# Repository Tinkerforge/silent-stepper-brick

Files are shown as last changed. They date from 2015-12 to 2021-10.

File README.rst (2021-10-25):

Silent Stepper Brick
====================

This repository contains the firmware source code and the hardware design
files. The documentation generator configs can be found at
https://github.com/Tinkerforge/generators

Repository Content
------------------

software/:
 * examples/: Examples for all supported languages
 * build/: Compiled files
 * src/: Source code of firmware
 * Makefile: Makefile to build project

hardware/:
 * Contains KiCad project files and additionally schematics as PDF

datasheets/:
 * Contains datasheets for sensors and complex ICs that are used

Hardware
--------

The hardware is designed with the open source EDA Suite KiCad
(http://www.kicad.org). Before you are able to open the files,
you have to install the Tinkerforge kicad-libraries
(https://github.com/Tinkerforge/kicad-libraries). You can either clone
them directly in hardware/ or clone them in a separate folder and
symlink them into hardware/
(ln -s kicad_path/kicad-libraries project_path/hardware). After that you
can open the .pro file in hardware/ with KiCad and from there view and
modify the schematics and the PCB layout.

Software
--------

If you want to do your own Brick/Bricklet firmware development we highly
recommend that you use our build environment setup script and read the
tutorial (https://www.tinkerforge.com/en/doc/Tutorials/Tutorial_Build_Environment/Tutorial.html).

To compile the C code we recommend you to install the newest GNU Arm Embedded
Toolchain (https://launchpad.net/gcc-arm-embedded/+download).
You also need to install bricklib (https://github.com/Tinkerforge/bricklib).

You can either clone it directly in software/src/ or clone it in a
separate folder and symlink it into software/src/
(ln -s bricklib_path/bricklib project_path/software/src/). Finally make sure to
have CMake installed (http://www.cmake.org/cmake/resources/software.html).

After that you can build the firmware by invoking make in software/.
The firmware (.bin) can then be found in software/build/ and uploaded
with brickv (click button "Flashing" on start screen).

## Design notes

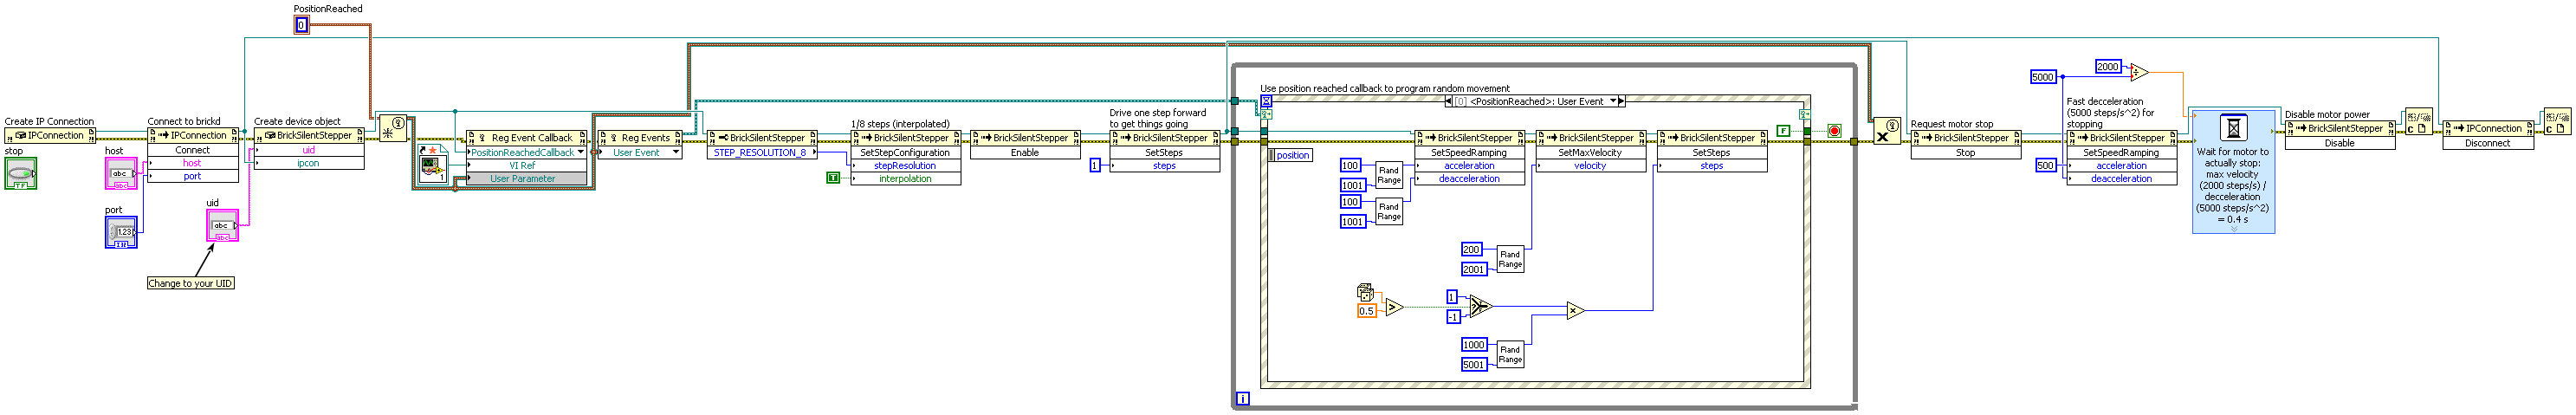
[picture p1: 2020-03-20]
software/examples/labview/Example Callback.vi.png

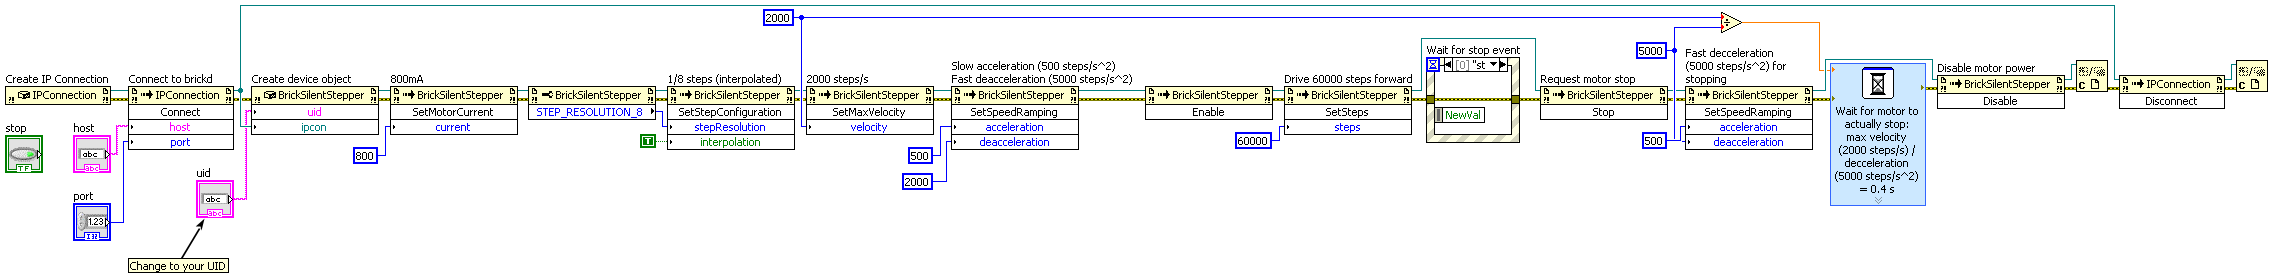
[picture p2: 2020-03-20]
software/examples/labview/Example Configuration.vi.png

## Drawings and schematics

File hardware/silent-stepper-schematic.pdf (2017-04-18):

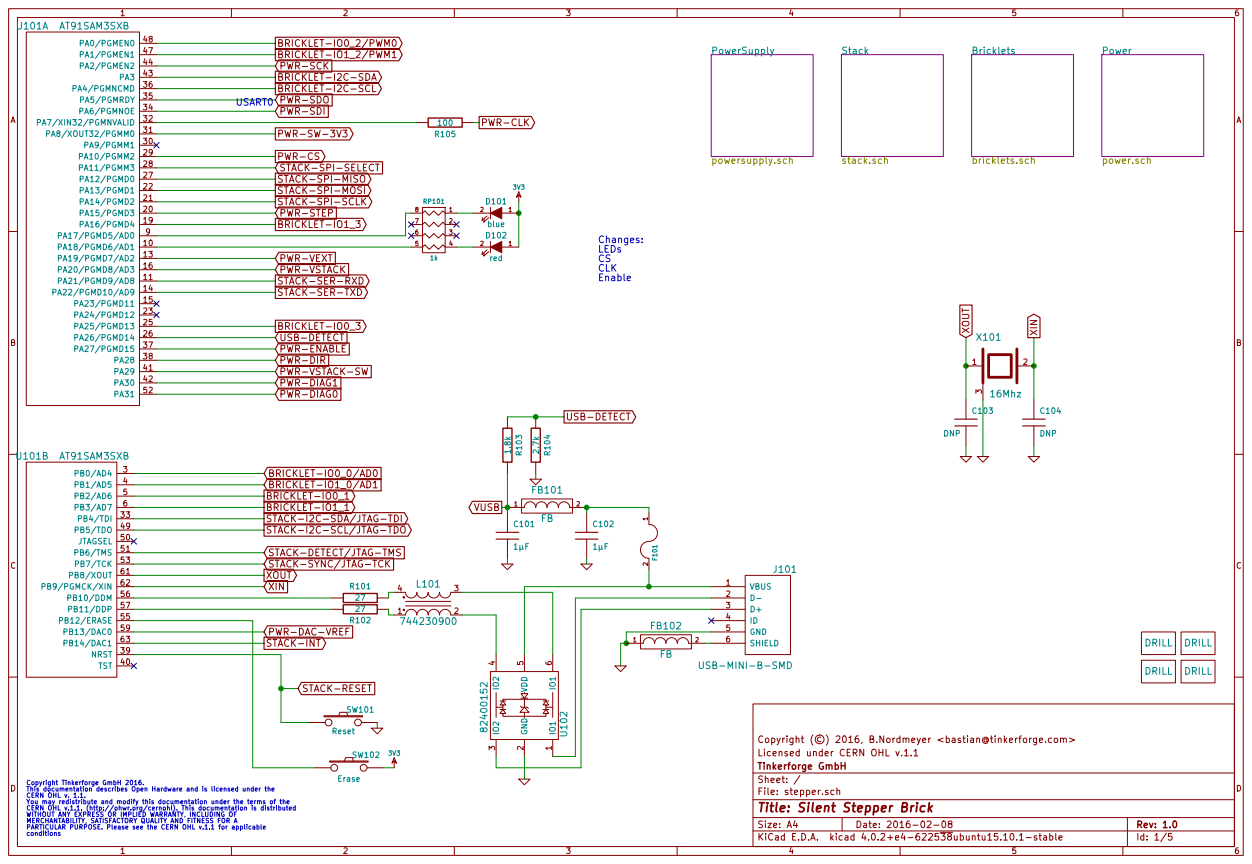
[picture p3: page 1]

BRICKLET-IO0_0/AD0
BRICKLET-IO1_0/AD1
BRICKLET-IO0_1
BRICKLET-IO1_1
STACK-I2C-SDA/JTAG-TDI
STACK-I2C-SCL/JTAG-TDO

STACK-DETECT/JTAG-TMS
STACK-SYNC/JTAG-TCK
XOUT
XIN

Licensed under CERN OHL v.1.1 Copyright (©) 2016, B.Nordmeyer <bastian@tinkerforge.com>

File: stepper.sch Sheet: / Tinkerforge GmbH

Copyright Tinkerforge GmbH 2016. This documentation describes Open Hardware and is licensed under the CERN OHL v. 1.1. You may redistribute and modify this documentation under the terms of the CERN OHL v.1.1. (http://ohwr.org/cernohl). This documentation is distributed WITHOUT ANY EXPRESS OR IMPLIED WARRANTY, INCLUDING OF MERCHANTABILITY, SATISFACTORY QUALITY AND FITNESS FOR A

Id: 1/5 Title: Silent Stepper Brick

PARTICULAR PURPOSE. Please see the CERN OHL v.1.1 for applicable
conditions

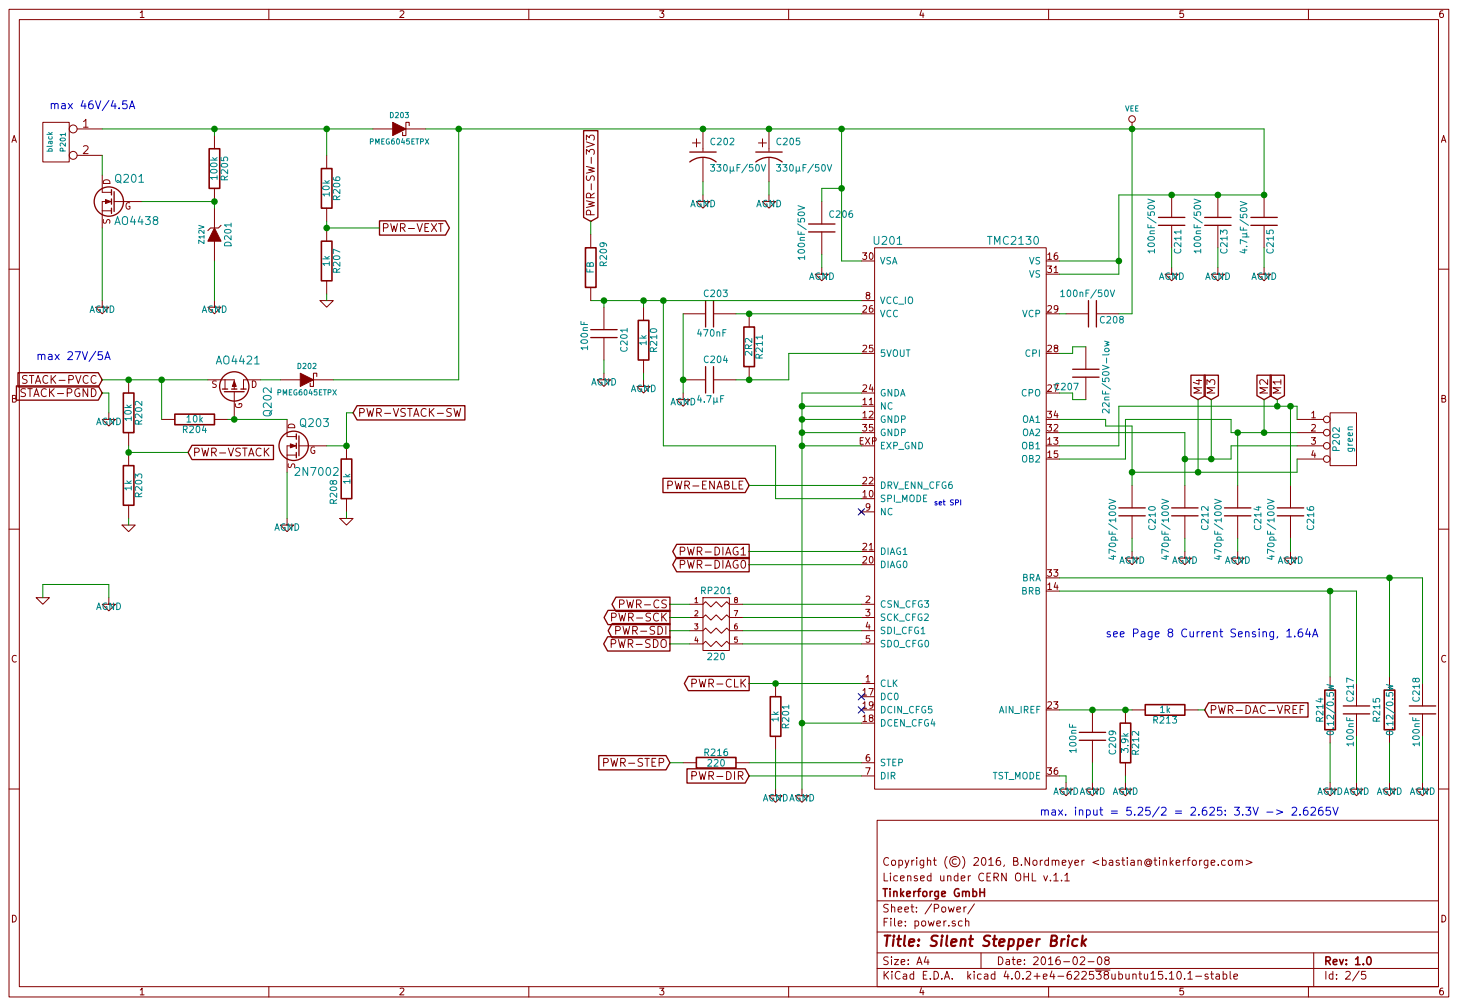
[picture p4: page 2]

File: power.sch Sheet: /Power/ Tinkerforge GmbH

Id: 2/5 Title: Silent Stepper Brick

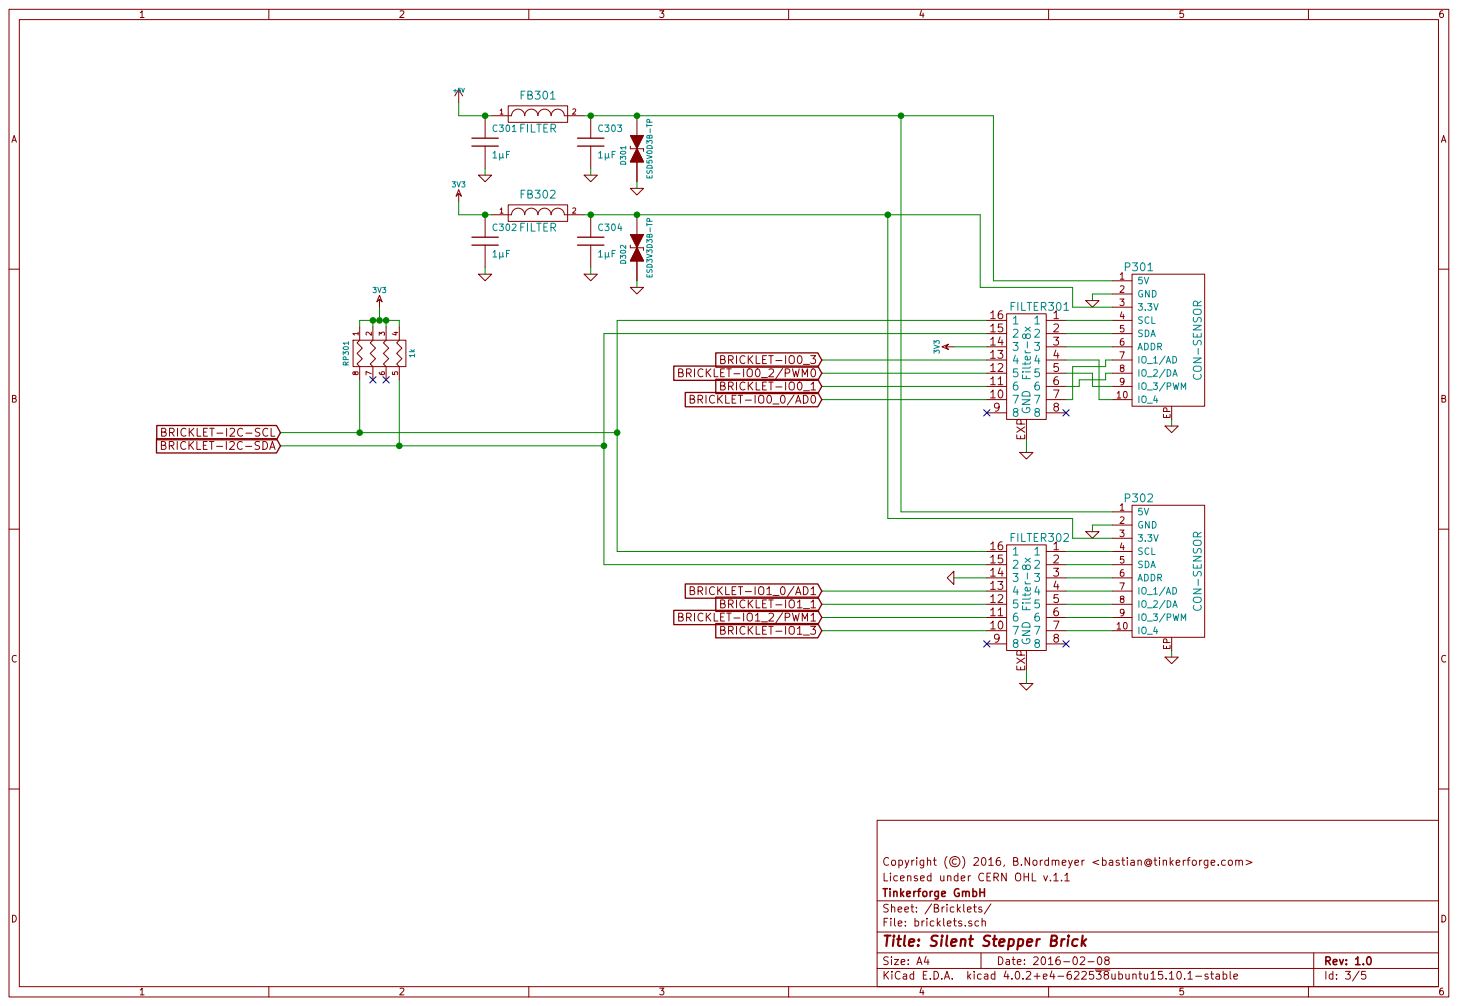
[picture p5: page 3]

File: bricklets.sch Sheet: /Bricklets/ Tinkerforge GmbH

Id: 3/5 Title: Silent Stepper Brick

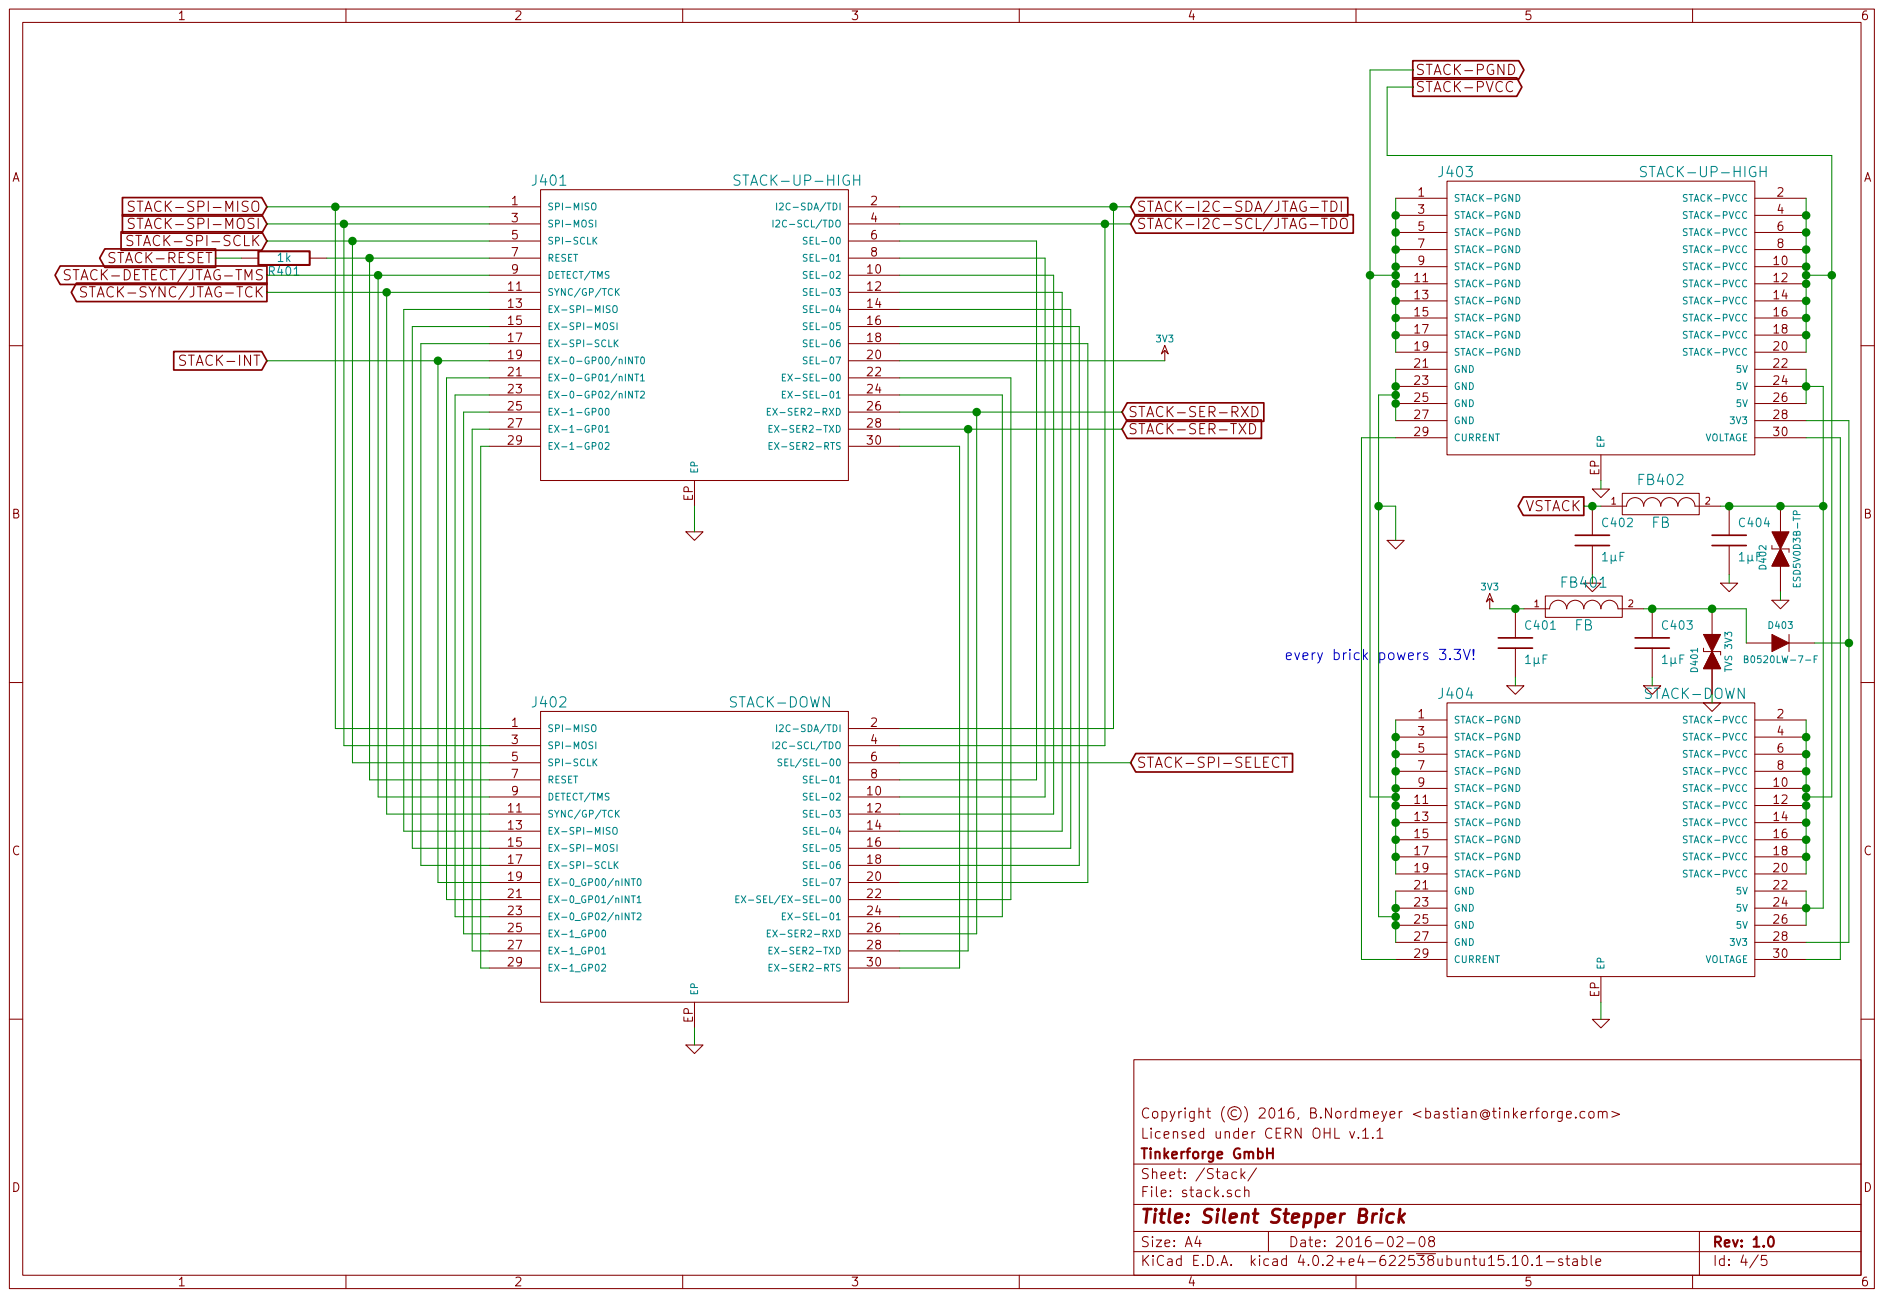
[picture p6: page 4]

STACK-SPI-MISO
STACK-SPI-MOSI
STACK-SPI-SCLK
STACK-RESET
STACK-DETECT/JTAG-TMS
STACK-SYNC/JTAG-TCK

STACK-I2C-SDA/JTAG-TDI
STACK-I2C-SCL/JTAG-TDO

Licensed under CERN OHL v.1.1 Copyright (©) 2016, B.Nordmeyer <bastian@tinkerforge.com>

File: stack.sch Sheet: /Stack/ Tinkerforge GmbH

Id: 4/5 Title: Silent Stepper Brick

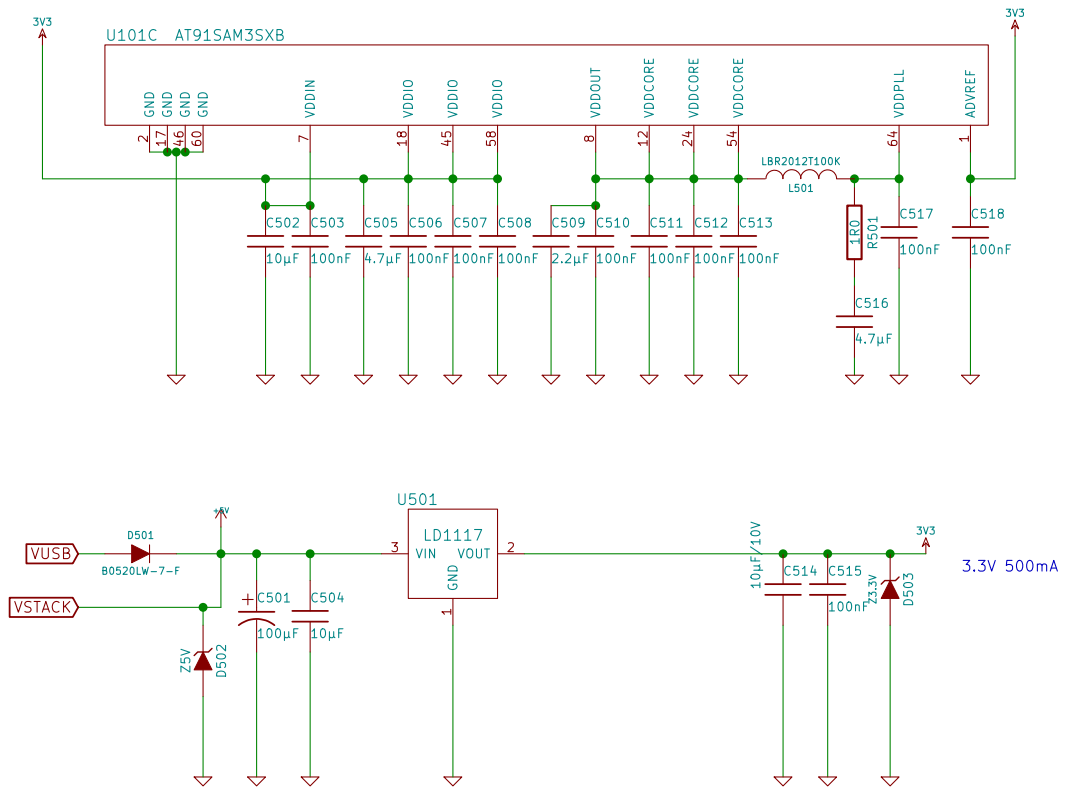
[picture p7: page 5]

8 GND 60 VDDCORE 12 VDDCORE 24 VDDCORE 54 VDDPLL 64 VDDIO 45 GND 46 GND 17 VDDIO 18 VDDIO 58

Licensed under CERN OHL v.1.1 Copyright (©) 2016, B.Nordmeyer <bastian@tinkerforge.com>

Tinkerforge GmbH
Sheet: /PowerSupply/
File: powersupply.sch
Id: 5/5 Title: Silent Stepper Brick

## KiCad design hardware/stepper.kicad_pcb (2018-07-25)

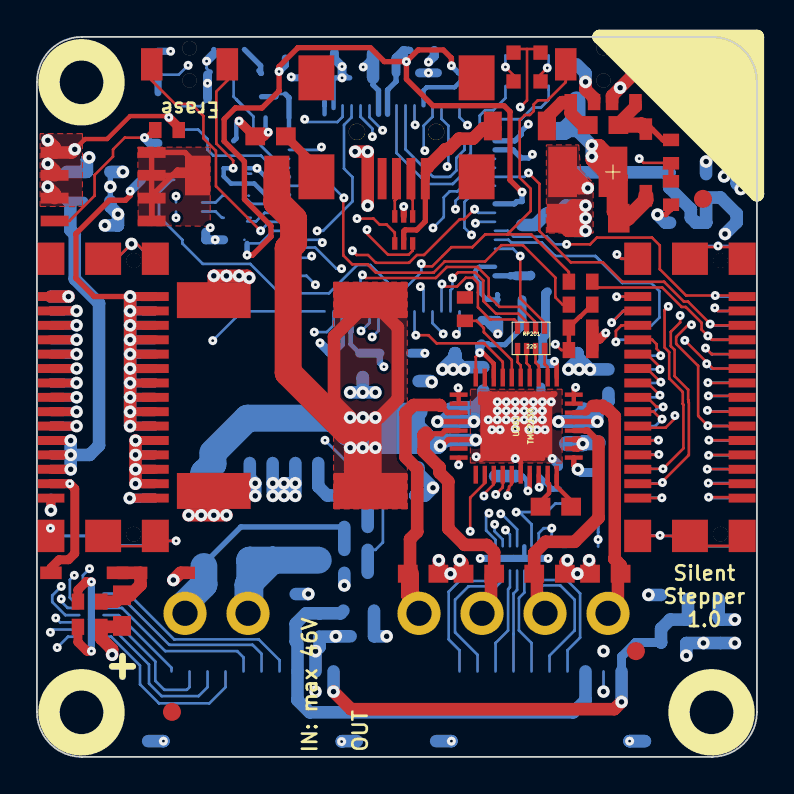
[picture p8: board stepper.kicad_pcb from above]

Board: 6 copper layers, 40.0 x 40.0 mm, 129 parts (0 on the bottom side), 129 nets.

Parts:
C101, C102, C301, C302, C303, C304, C401, C402, C403, C404: 1µF; C0402E
C103, C104: DNP; C0402E
C201, C209, C217, C218, C503, C506, C507, C508, C510, C511, C512, C513, C515, C517, C518: 100nF; C0402E
C202, C205: 330µF/50V; ELKO_103
C203: 470nF; C0402E
C204, C505, C516: 4.7µF; C0603E
C206, C208, C211, C213: 100nF/50V; C0603E
C207: 22nF/50V-low; C0603E
C210, C212, C214, C216: 470pF/100V; C0603E
C215: 4.7µF/50V; C1206
C501: 100µF; 3528-21
C502, C504: 10µF; C0805
C509: 2.2µF; C0603E
C514: 10µF/10V; C0805
D101: blue; D0603
D102: red; D0603
D201: Z12V; SOD-123
D202, D203: PMEG6045ETPX; SOD-128
D301, D402: ESD5V0D3B-TP; SOD-323
D302: ESD3V3D3B-TP; SOD-323
D401: TVS 3V3; SOD-323
D403, D501: B0520LW-7-F; SOD-123
D502: Z5V; MiniMelf
D503: Z3.3V; MiniMelf
F101: PTC; C1206
FB101, FB102, FB401, FB402: FB; C0603E
FB301, FB302: FILTER; C0603E
FILTER301, FILTER302: Filter-8x; DFN16-33x135
Fiducial_Mark: VAL**; Fiducial_Mark
Fiducial_Mark#2, Fiducial_Mark#3, Fiducial_Mark#4, Fiducial_Mark#5, Fiducial_Mark#6: VAL**; Fiducial_Mark
J101: USB-MINI-B-SMD
J102, J103, J104, J105: DRILL; DRILL_NP
J401, J403: STACK-UP-HIGH; BTB08-ACS-TOP
J402, J404: STACK-DOWN; BTB08-ACS-BTM
L101: 744230900; WE-CNSW-0603
L501: LBR2012T100K; C0805
P201: black; OQ_2P
P202: green; OQ_4P
P301, P302: CON-SENSOR
Q201: AO4438; SOIC-8-MOSFET
Q202: AO4421; SOIC-8-MOSFET
Q203: 2N7002; SOT23GDS
R101, R102: 27; R0402E
R103: 1.8k; R0402E
R104: 2.7k; R0402E
R105: 100; R0402E
R201, R203, R207, R208, R210, R213, R401: 1k; R0402E
R202, R204, R206: 10k; R0402E
R205: 100k; R0402E
R209: FB; C0402E
R211: 2R2; R0402E
R212: 3.9k; R0402E
R214, R215: 0.12/0.5W; R1206
R216: 220; R0402E
R501: 1R0; R0402E
RP101, RP301: 1k; 4X0603
RP201: 220; 4X0402
SW101: Reset; TACT-SWITCH
SW102: Erase; TACT-SWITCH
U101: AT91SAM3SXB; LQFP64
U102: 82400152; SOT563-SPEC
U201: TMC2130; QFN36_5X6
U501: LD1117; SOT-223
VAL: WEEE_7mm_back
VAL#2: CE_5mm
X101: 16Mhz; CRYSTAL_3225

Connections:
3V3: C302.1, C401.1, C502.1, C503.1, C505.1, C506.1, C507.1, C508.1, C514.1, C515.1, C518.1, D101.1, D102.1, D503.2, FB302.1, FB401.1, FILTER301.14, J401.20, RP301.1, RP301.2, RP301.3, RP301.4, SW102.2, U101.1, U101.7, U101.18, U101.45, U101.58, U501.2
BRICKLET-I2C-SCL: FILTER301.16, FILTER302.16, RP301.8, U101.36
BRICKLET-I2C-SDA: FILTER301.15, FILTER302.15, RP301.5, U101.43
BRICKLET-IO0_0/AD0: FILTER301.10, U101.3
BRICKLET-IO0_1: FILTER301.11, U101.5
BRICKLET-IO0_2/PWM0: FILTER301.12, U101.48
BRICKLET-IO0_3: FILTER301.13, U101.25
BRICKLET-IO1_0/AD1: FILTER302.13, U101.4
BRICKLET-IO1_1: FILTER302.12, U101.6
BRICKLET-IO1_2/PWM1: FILTER302.11, U101.47
BRICKLET-IO1_3: FILTER302.10, U101.19
M1: C216.2, P202.1, U201.13
M2: C214.2, P202.2, U201.15
M3: C212.2, P202.3, U201.32
M4: C210.2, P202.4, U201.34
unnamed: C102.1, F101.1, FB101.2
unnamed: C201.2, R209.2, R210.1, U201.8, U201.10
unnamed: C203.1, R211.1, U201.26
unnamed: C204.1, R211.2, U201.25
unnamed: C207.1, U201.27
unnamed: C207.2, U201.28
unnamed: C208.2, U201.29
unnamed: C209.2, R212.1, R213.2, U201.23
unnamed: C217.2, R214.2, U201.14
unnamed: C218.2, R215.2, U201.33
unnamed: C303.1, D301.2, FB301.2, P301.1, P302.1
unnamed: C304.1, D302.2, FB302.2, P301.3, P302.3
unnamed: C403.1, D401.2, D403.1, FB401.2
unnamed: C404.1, D402.2, FB402.2, J403.22, J403.24, J403.26, J404.22, J404.24, J404.26
unnamed: C509.1, C510.1, C511.1, C512.1, C513.1, L501.1, U101.8, U101.12, U101.24, U101.54
unnamed: C516.1, R501.1
unnamed: C517.1, L501.2, R501.2, U101.64
unnamed: D101.2, RP101.1
unnamed: D102.2, RP101.4
unnamed: D201.2, Q201.G, R205.2
unnamed: D202.1, Q202.D
unnamed: D203.1, P201.1, R205.1, R206.1
unnamed: D403.2, J403.28, J404.28
unnamed: F101.2, J101.1, U102.5
unnamed: FB102.2, J101.6
unnamed: FILTER301.1, P301.4
unnamed: FILTER301.2, P301.5
unnamed: FILTER301.3, P301.6
unnamed: FILTER301.4, P301.10
unnamed: FILTER301.5, P301.9
unnamed: FILTER301.6, P301.8
unnamed: FILTER301.7, P301.7
unnamed: FILTER302.1, P302.4
unnamed: FILTER302.2, P302.5
unnamed: FILTER302.3, P302.6
unnamed: FILTER302.4, P302.7
unnamed: FILTER302.5, P302.8
unnamed: FILTER302.6, P302.9
unnamed: FILTER302.7, P302.10
unnamed: J101.2, U102.1
unnamed: J101.3, U102.3
unnamed: J401.6, J402.8
unnamed: J401.7, J402.7, R401.1
unnamed: J401.8, J402.10
unnamed: J401.10, J402.12
unnamed: J401.12, J402.14
unnamed: J401.13, J402.13
unnamed: J401.14, J402.16
unnamed: J401.15, J402.15
unnamed: J401.16, J402.18
unnamed: J401.17, J402.17
unnamed: J401.18, J402.20
unnamed: J401.21, J402.21
unnamed: J401.22, J402.22
unnamed: J401.23, J402.23
unnamed: J401.24, J402.24
unnamed: J401.25, J402.25
unnamed: J401.27, J402.27
unnamed: J401.29, J402.29
unnamed: J401.30, J402.30
unnamed: J403.29, J404.29
unnamed: J403.30, J404.30
unnamed: L101.1, R102.1
unnamed: L101.2, U102.4
unnamed: L101.3, U102.6
unnamed: L101.4, R101.1
unnamed: P201.2, Q201.D
unnamed: Q202.G, Q203.D, R204.1
unnamed: R101.2, U101.56
unnamed: R102.2, U101.57
unnamed: R105.1, U101.32
unnamed: R216.2, U201.6
unnamed: RP101.5, U101.10
unnamed: RP101.8, U101.9
unnamed: RP201.5, U201.5
unnamed: RP201.6, U201.4
unnamed: RP201.7, U201.3
unnamed: RP201.8, U201.2
unnamed: SW102.1, U101.55
PWR-CLK: R105.2, R201.1, U201.1
PWR-CS: RP201.1, U101.29
PWR-DAC-VREF: R213.1, U101.59
PWR-DIAG0: U101.52, U201.20
PWR-DIAG1: U101.42, U201.21
PWR-DIR: U101.38, U201.7
PWR-ENABLE: U101.37, U201.22
PWR-SCK: RP201.2, U101.44
PWR-SDI: RP201.3, U101.34
PWR-SDO: RP201.4, U101.35
PWR-STEP: R216.1, U101.20
PWR-SW-3V3: R209.1, U101.31
PWR-VEXT: R206.2, R207.1, U101.13
PWR-VSTACK: R202.2, R203.1, U101.16
PWR-VSTACK-SW: Q203.G, R208.2, U101.41
STACK-DETECT/JTAG-TMS: J401.9, J402.9, U101.51
STACK-I2C-SCL/JTAG-TDO: J401.4, J402.4, U101.49
STACK-I2C-SDA/JTAG-TDI: J401.2, J402.2, U101.33
STACK-INT: J401.19, J402.19, U101.63
STACK-PGND: C101.2, C102.2, C103.2, C104.2, C201.1, C202.2, C203.2, C204.2, C205.2, C206.2, C209.1, C210.1, C211.2, C212.1, C213.2, C214.1, C215.2, C216.1, C217.1, C218.1, C301.2, C302.2, C303.2, C304.2, C401.2, C402.2, C403.2, C404.2, C501.2, C502.2, C503.2, C504.2, C505.2, C506.2, C507.2, C508.2, C509.2, C510.2, C511.2, C512.2, C513.2, C514.2, C515.2, C516.2, C517.2, C518.2, D201.1, D301.1, D302.1, D401.1, D402.1, D502.1, D503.1, FB102.1, FILTER301.EXP, FILTER302.14, FILTER302.EXP, J101.5, J401.EP, J402.EP, J403.1, J403.3, J403.5, J403.7, J403.9, J403.11, J403.13, J403.15, J403.17, J403.19, J403.21, J403.23, J403.25, J403.27, J403.EP, J404.1, J404.3, J404.5, J404.7, J404.9, J404.11, J404.13, J404.15, J404.17, J404.19, J404.21, J404.23, J404.25, J404.27, J404.EP, P301.2, P301.EP, P302.2, P302.EP, Q201.S, Q203.S, R104.1, R201.2, R203.2, R207.2, R208.1, R210.2, R212.2, R214.1, R215.1, SW101.2, U101.2, U101.17, U101.46, U101.60, U102.2, U201.11, U201.12, U201.18, U201.24, U201.35, U201.36, U201.EXP, U501.1, X101.3
STACK-PVCC: J403.2, J403.4, J403.6, J403.8, J403.10, J403.12, J403.14, J403.16, J403.18, J403.20, J404.2, J404.4, J404.6, J404.8, J404.10, J404.12, J404.14, J404.16, J404.18, J404.20, Q202.S, R202.1, R204.2
STACK-RESET: R401.2, SW101.1, U101.39
STACK-SER-RXD: J401.26, J402.26, U101.11
STACK-SER-TXD: J401.28, J402.28, U101.14
STACK-SPI-MISO: J401.1, J402.1, U101.27
STACK-SPI-MOSI: J401.3, J402.3, U101.22
STACK-SPI-SCLK: J401.5, J402.5, U101.21
STACK-SPI-SELECT: J402.6, U101.28
STACK-SYNC/JTAG-TCK: J401.11, J402.11, U101.53
USB-DETECT: R103.2, R104.2, U101.26
VEE: C202.1, C205.1, C206.1, C208.1, C211.1, C213.1, C215.1, D202.2, D203.2, U201.16, U201.30, U201.31
VSTACK: C301.1, C402.1, C501.1, C504.1, D501.2, D502.2, FB301.1, FB402.1, U501.3
VUSB: C101.1, D501.1, FB101.1, R103.1
XIN: C104.1, U101.62, X101.2
XOUT: C103.1, U101.61, X101.1

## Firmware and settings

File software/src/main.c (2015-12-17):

/* silent-stepper-brick
 * Copyright (C) 2015 Olaf Lüke <olaf@tinkerforge.com>
 *
 * main.c: Silent Stepper Brick startup code
 *
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
 * You should have received a copy of the GNU Lesser General Public
 * License along with this library; if not, write to the
 * Free Software Foundation, Inc., 59 Temple Place - Suite 330,
 * Boston, MA 02111-1307, USA.
 */

#include <stdbool.h>
#include <stdint.h>
#include <stdio.h>
#include <stdlib.h>

#include "bricklib/free_rtos/include/FreeRTOS.h"
#include "bricklib/free_rtos/include/task.h"

#include "bricklib/com/i2c/i2c_pca9549/i2c_pca9549.h"
#include "bricklib/com/spi/spi_stack/spi_stack_master.h"
#include "bricklib/com/spi/spi_stack/spi_stack_slave.h"
#include "bricklib/com/spi/spi_stack/spi_stack_common.h"
#include "bricklib/com/i2c/i2c_eeprom/i2c_eeprom_master.h"
#include "bricklib/com/i2c/i2c_eeprom/i2c_eeprom_slave.h"
#include "bricklib/com/usb/usb.h"
#include "bricklib/logging/logging.h"
#include "bricklib/bricklet/bricklet_init.h"
#include "bricklib/drivers/uid/uid.h"
#include "bricklib/drivers/wdt/wdt.h"
#include "bricklib/drivers/pio/pio.h"
#include "bricklib/utility/init.h"
#include "bricklib/utility/profiling.h"
#include "bricklib/utility/led.h"
#include "bricklib/logging/logging.h"

#include "config.h"
#include "communication.h"
#include "silent-stepper.h"

uint8_t brick_hardware_version[3];
extern bool usb_first_connection;

void vApplicationStackOverflowHook(xTaskHandle *pxTask, signed char *pcTaskName) {
	logf("Stack Overflow\n\r");
	while(true);
}

int main() {
	brick_hardware_version[0] = BRICK_HARDWARE_VERSION_MAJOR;
	brick_hardware_version[1] = BRICK_HARDWARE_VERSION_MINOR;
	brick_hardware_version[2] = BRICK_HARDWARE_VERSION_REVISION;

	brick_init();
	wdt_restart();

    if(usb_is_connected()) {
    	logi("Configure as USB device\n\r");
    	usb_init();
    	wdt_restart();

    	xTaskCreate(usb_message_loop,
    				(signed char *)"usb_ml",
    				1000,
    				NULL,
    				1,
    				(xTaskHandle *)NULL);
    } else {
    	logi("Configure as Stack Participant (SPI)\n\r");
    	usb_first_connection = false;
        spi_stack_slave_init();
    	wdt_restart();

    	xTaskCreate(spi_stack_slave_message_loop,
    			    (signed char *)"spi_ml",
    			    2500,
    			    NULL,
    			    1,
    			    (xTaskHandle *)NULL);
    }

	stepper_init();
    wdt_restart();

	brick_init_start_tick_task();
    wdt_restart();

	vTaskStartScheduler();
}

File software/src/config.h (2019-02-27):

/* silent-stepper-brick
 * Copyright (C) 2015 Olaf Lüke <olaf@tinkerforge.com>
 *
 * config.h: Silent Stepper Brick specific configuration
 *
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
 * You should have received a copy of the GNU Lesser General Public
 * License along with this library; if not, write to the
 * Free Software Foundation, Inc., 59 Temple Place - Suite 330,
 * Boston, MA 02111-1307, USA.
 */

#ifndef CONFIG_H
#define CONFIG_H

#include "communication.h"
#include "bricklib/drivers/board/sam3s/SAM3S.h"
#include "silent-stepper.h"

#define BRICK_FIRMWARE_VERSION_MAJOR 2
#define BRICK_FIRMWARE_VERSION_MINOR 0
#define BRICK_FIRMWARE_VERSION_REVISION 8

#define BRICK_HARDWARE_VERSION_MAJOR 1
#define BRICK_HARDWARE_VERSION_MINOR 0
#define BRICK_HARDWARE_VERSION_REVISION 0

#define BRICK_DEVICE_IDENTIFIER 19

// ************** DEBUG SETTINGS **************
#define DEBUG_SPI_STACK 1
#define DEBUG_I2C_EEPROM 0
#define DEBUG_STARTUP 1
#define DEBUG_BRICKLET 1
#define DEBUG_STEPPER 1
//#define PROFILING
//#define PROFILING_TIME 100 // After how many seconds profiling is printed

#define DISABLE_JTAG_ON_STARTUP
//#define LOGGING_SERIAL
//#define LOGGING_LEVEL LOGGING_DEBUG
#define LOGGING_LEVEL LOGGING_NONE


// ************** BRICK SETTINGS **************

// Frequencies
#define BOARD_MCK      64000000 // Frequency of brick
#define BOARD_MAINOSC  16000000 // Frequency of oscillator
#define BOARD_ADC_FREQ 16000000 // Frequency of ADC
#define BOARD_OSC_EXTERNAL      // Use external oscillator
#define SPI_FREQ       2000000  // Frequency of SPI communication to TMC2130

#define BRICK_HAS_CO_MCU_SUPPORT

// UART for console output (printf)
#define PIN_CONSOLE_RXD  {1 << 21, PIOA, ID_PIOA, PIO_PERIPH_A, PIO_DEFAULT}
#define PIN_CONSOLE_TXD  {1 << 22, PIOA, ID_PIOA, PIO_PERIPH_A, PIO_DEFAULT}

#define CONSOLE_BAUDRATE 115200
#define CONSOLE_USART    USART1
#define CONSOLE_ID       ID_USART1
#define CONSOLE_PINS     {PIN_CONSOLE_RXD, PIN_CONSOLE_TXD}

#define PINS_UART        {PIN_CONSOLE_RXD, PIN_CONSOLE_TXD}

// TWI
// TWI version
#define TWI_V3XX

// TWI stack definitions (for reading of eeproms from Bricks in stack)
#define TWI_STACK           TWI1
#define PIN_TWI_TWD_STACK   {1 << 4, PIOB, ID_PIOB, PIO_PERIPH_A, PIO_DEFAULT}
#define PIN_TWI_TWCK_STACK  {1 << 5, PIOB, ID_PIOB, PIO_PERIPH_A, PIO_DEFAULT}
#define PINS_TWI_STACK      PIN_TWI_TWD_STACK, PIN_TWI_TWCK_STACK

// TWI bricklet definitions (for bricklets, spi select and brick specific
//                           functions)
#define TWI_BRICKLET           TWI0
#define PIN_TWI_TWD_BRICKLET   {1 << 3, PIOA, ID_PIOA, PIO_PERIPH_A, PIO_DEFAULT}
#define PIN_TWI_TWCK_BRICKLET  {1 << 4, PIOA, ID_PIOA, PIO_PERIPH_A, PIO_DEFAULT}
#define PINS_TWI_BRICKLET      PIN_TWI_TWD_BRICKLET, PIN_TWI_TWCK_BRICKLET

// USB
// USB VBUS monitoring pin for USB plug and play
#define PIN_USB_DETECT  {1 << 26, PIOA, ID_PIOA, PIO_INPUT, PIO_DEFAULT}
// USB product descriptor (name of brick)
#define PRODUCT_DESCRIPTOR { \
	USBStringDescriptor_LENGTH(20), \
    USBGenericDescriptor_STRING, \
    USBStringDescriptor_UNICODE('S'), \
    USBStringDescriptor_UNICODE('i'), \
    USBStringDescriptor_UNICODE('l'), \
    USBStringDescriptor_UNICODE('e'), \
    USBStringDescriptor_UNICODE('n'), \
    USBStringDescriptor_UNICODE('t'), \
    USBStringDescriptor_UNICODE(' '), \
    USBStringDescriptor_UNICODE('S'), \
    USBStringDescriptor_UNICODE('t'), \
    USBStringDescriptor_UNICODE('e'), \
    USBStringDescriptor_UNICODE('p'), \
    USBStringDescriptor_UNICODE('p'), \
    USBStringDescriptor_UNICODE('e'), \
    USBStringDescriptor_UNICODE('r'), \
    USBStringDescriptor_UNICODE(' '), \
    USBStringDescriptor_UNICODE('B'), \
    USBStringDescriptor_UNICODE('r'), \
    USBStringDescriptor_UNICODE('i'), \
    USBStringDescriptor_UNICODE('c'), \
    USBStringDescriptor_UNICODE('k') \
}


// SPI
#define PIN_SPI_MISO        {1 << 12, PIOA, ID_PIOA, PIO_PERIPH_A, PIO_DEFAULT}
#define PIN_SPI_MOSI        {1 << 13, PIOA, ID_PIOA, PIO_PERIPH_A, PIO_DEFAULT}
#define PIN_SPI_SPCK        {1 << 14, PIOA, ID_PIOA, PIO_PERIPH_A, PIO_DEFAULT}

#define PINS_SPI            PIN_SPI_MISO, PIN_SPI_MOSI, PIN_SPI_SPCK

#define PIN_SPI_SELECT_SLAVE  {1 << 11, PIOA, ID_PIOA, PIO_PERIPH_A, PIO_DEFAULT}

// LED
#define PIN_LED_STD_BLUE    {1 << 17, PIOA, ID_PIOA, PIO_OUTPUT_1, PIO_DEFAULT}
#define PIN_LED_STD_RED     {1 << 18, PIOA, ID_PIOA, PIO_OUTPUT_1, PIO_DEFAULT}
#define PINS_STD_LED        PIN_LED_STD_BLUE, PIN_LED_STD_RED 
#define PINS_LED            PINS_STD_LED

#define LED_STD_BLUE        0
#define LED_STD_RED         1


// Brick Detect
// Set low by master
// TODO: Change name
#define PIN_DETECT        {1 << 6, PIOB, ID_PIOB, PIO_OUTPUT_0, PIO_DEFAULT}
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

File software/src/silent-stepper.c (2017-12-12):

/* silent-stepper-brick
 * Copyright (C) 2015 Olaf Lüke <olaf@tinkerforge.com>
 *
 * silent-stepper.c: Implementation of Silent Stepper Brick specific functions
 *
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
 * You should have received a copy of the GNU Lesser General Public
 * License along with this library; if not, write to the
 * Free Software Foundation, Inc., 59 Temple Place - Suite 330,
 * Boston, MA 02111-1307, USA.
 */

#include "silent-stepper.h"

#include <stdio.h>
#include "tmc2130.h"

#include "config.h"
#include "communication.h"
#include "bricklib/com/com.h"
#include "bricklib/com/com_common.h"
#include "bricklib/logging/logging.h"
#include "bricklib/bricklet/bricklet_init.h"
#include "bricklib/drivers/dacc/dacc.h"
#include "bricklib/drivers/adc/adc.h"
#include "bricklib/drivers/tc/tc.h"
#include "bricklib/drivers/pio/pio.h"
#include "bricklib/drivers/usart/usart.h"
#include "bricklib/drivers/pwmc/pwmc.h"
#include "bricklib/drivers/usb/USBD_HAL.h"
#include "bricklib/utility/util_definitions.h"
#include "bricklib/utility/led.h"
#include "bricklib/utility/init.h"

extern TMC2130HighLevel tmc2130_high_level;
extern TMC2130RegDRV_STATUS tmc2130_reg_drv_status;


Pin pin_voltage_switch = VOLTAGE_STACK_SWITCH_PIN;

Pin pin_enable =  PIN_ENABLE;
Pin pin_step = PIN_STEP;
Pin pin_direction = PIN_DIRECTION;
Pin pin_vref = PIN_VREF;


uint32_t stepper_velocity_goal = STEPPER_VELOCITY_DEFAULT;
uint32_t stepper_velocity = 0;
uint16_t stepper_acceleration = STEPPER_ACCELERATION_DEFAULT;
uint16_t stepper_acceleration_sqrt = STEPPER_ACCELERATION_SQRT_DEFAULT;
uint16_t stepper_deceleration = STEPPER_DECELERATION_DEFAUL;
uint16_t stepper_minimum_voltage = STEPPER_MINIMUM_VOLTAGE_DEFAULT;

int32_t stepper_position = 0;
int32_t stepper_target_position = 0;
int32_t stepper_steps = 0;
uint16_t stepper_output_current = STEPPER_OUTPUT_CURRENT_DEFAULT;
int8_t stepper_state = STEPPER_STATE_OFF;
int8_t stepper_speedramp_state = STEPPER_SPEEDRAMP_STATE_STOP;
int8_t stepper_direction = STEPPER_DIRECTION_FORWARD;

int32_t stepper_step_counter = 0;
int32_t stepper_acceleration_counter = 0;
uint32_t stepper_acceleration_steps = 0;
int32_t stepper_deceleration_steps = 0;
int32_t stepper_delay = 0;
int32_t stepper_last_delay = 0;
int32_t stepper_delay_rest = 0;
int32_t stepper_deceleration_start = 0;
uint32_t stepper_tick_counter = 0;
uint8_t stepper_tick_read_counter = 0;

uint32_t stepper_time_base = 1;
uint32_t stepper_time_base_counter = 1;
uint32_t stepper_all_data_period = 0;
uint32_t stepper_all_data_period_counter = 0;

bool stepper_running = false;
bool stepper_position_reached = false;

uint8_t stepper_api_state = STEPPER_API_STATE_STOP;
uint8_t stepper_api_prev_state = STEPPER_API_STATE_STOP;
bool stepper_api_state_send = false;

bool silent_mode_switched = false;

const uint32_t stepper_timer_frequency[] = {BOARD_MCK/2,
                                            BOARD_MCK/8,
                                            BOARD_MCK/32,
                                            BOARD_MCK/128,
                                            32768};
const uint32_t stepper_timer_velocity[]  = {BOARD_MCK/2   / MAX_TIMER_VALUE,
                                            BOARD_MCK/8   / MAX_TIMER_VALUE,
                                            BOARD_MCK/32  / MAX_TIMER_VALUE,
                                            BOARD_MCK/128 / MAX_TIMER_VALUE,
                                            32768         / MAX_TIMER_VALUE};

extern ComInfo com_info;

void stepper_position_reached_signal(void) {
	PositionReachedSignal prs;
	com_make_default_header(&prs, com_info.uid, sizeof(PositionReachedSignal), FID_POSITION_REACHED);
	prs.position = stepper_position;

	send_blocking_with_timeout(&prs,
	                           sizeof(PositionReachedSignal),
	                           com_info.current);
}

void stepper_check_error_signals(void) {
	if(stepper_tick_counter % 1000 != 0 || stepper_state == STEPPER_STATE_OFF) {
		return;
	}

	const uint16_t external_voltage = stepper_get_external_voltage();
	const uint16_t stack_voltage    = stepper_get_stack_voltage();

	// Under Voltage if external voltage is below minimum voltage (regardless
	// of stack voltage), or if external voltage is zero and stack velotage is
	// below minimum voltage

	if((external_voltage > STEPPER_VOLTAGE_EPSILON &&
	    external_voltage < stepper_minimum_voltage) ||
	   (external_voltage < STEPPER_VOLTAGE_EPSILON &&
	    stack_voltage > STEPPER_VOLTAGE_EPSILON &&
	    stack_voltage < stepper_minimum_voltage)) {
		UnderVoltageSignal uvs;
		com_make_default_header(&uvs, com_info.uid, sizeof(UnderVoltageSignal), FID_UNDER_VOLTAGE);
		uvs.voltage = external_voltage < STEPPER_VOLTAGE_EPSILON ? stack_voltage : external_voltage;

		send_blocking_with_timeout(&uvs,
		                           sizeof(UnderVoltageSignal),
		                           com_info.current);
		led_on(LED_STD_RED);
	} else {
		led_off(LED_STD_RED);
	}
}

void stepper_make_drive_speedramp(const uint8_t state) {
	stepper_state = STEPPER_STATE_DRIVE;
	stepper_speedramp_state = state;

	if(state == STEPPER_SPEEDRAMP_STATE_STOP) {
		stepper_set_new_api_state(STEPPER_API_STATE_DECELERATION);
	} else if(state == STEPPER_SPEEDRAMP_STATE_BACKWARD ||
	          state == STEPPER_SPEEDRAMP_STATE_FORWARD) {
		stepper_set_new_api_state(STEPPER_API_STATE_ACCELERATION);
	}

	if(!stepper_is_currently_running()) {
		// call drive speedramp one time, to get it going
		// (i.e. make velocity != 0)
		stepper_drive_speedramp();
		TC0_IrqHandler();
	}
}
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

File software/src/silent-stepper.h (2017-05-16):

/* silent-stepper-brick
 * Copyright (C) 2015-2016 Olaf Lüke <olaf@tinkerforge.com>
 *
 * silent-stepper.h: Implementation of Silent Stepper Brick specific functions
 *
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
 * You should have received a copy of the GNU Lesser General Public
 * License along with this library; if not, write to the
 * Free Software Foundation, Inc., 59 Temple Place - Suite 330,
 * Boston, MA 02111-1307, USA.
 */

#ifndef STEPPER_H
#define STEPPER_H

#include <stdint.h>
#include "config.h"
#include "bricklib/utility/util_definitions.h"

#define STEPPER_VELOCITY_DEFAULT           500
#define STEPPER_ACCELERATION_DEFAULT       1000
#define STEPPER_ACCELERATION_SQRT_DEFAULT  31 // sqrt(1000)
#define STEPPER_DECELERATION_DEFAUL        1000
#define STEPPER_MINIMUM_VOLTAGE_DEFAULT    8000
#define STEPPER_VOLTAGE_EPSILON            6000
#define STEPPER_OUTPUT_CURRENT_DEFAULT     800

#define VELOCITY_TO_DELAY(vel) ((2147483647/2)/(vel))
#define DELAY_TO_VELOCITY(del) ((2147483647/2)/(del))

#define MAX_TIMER_VALUE 0xFFFF

#define STEPPER_READ_REGISTER_PERIOD 10

#define STEPPER_PWM_MAX_DUTY_CYCLE 128

#define STEPPER_TC_CHANNEL_NUM 0
#define STEPPER_TC_CHANNEL (TC0->TC_CHANNEL[STEPPER_TC_CHANNEL_NUM])
#define STEPPER_COUNTER STEPPER_TC_CHANNEL.TC_RC

#define STEPPER_CLK_CHANNEL_NUM 2
#define STEPPER_CLK_CHANNEL (TC0->TC_CHANNEL[STEPPER_CLK_CHANNEL_NUM])

// (0.2*3300)
#define DECAY_MIN_VALUE      SCALE(660, VOLTAGE_MIN_DAC, VOLTAGE_MAX_DAC, \
                                        VOLTAGE_MIN_VALUE, VOLTAGE_MAX_VALUE)
// (0.61*3300)
#define DECAY_MAX_VALUE      SCALE(2013, VOLTAGE_MIN_DAC, VOLTAGE_MAX_DAC, \
                                         VOLTAGE_MIN_VALUE, VOLTAGE_MAX_VALUE)

#define DECAY_DEFAULT_VALUE  10000

#define STEPPER_STATE_OFF    1
#define STEPPER_STATE_STOP   2
#define STEPPER_STATE_DRIVE  3
#define STEPPER_STATE_STEPS  4
#define STEPPER_STATE_TARGET 5

// Define forward and backward same as for direction,
// this allows for easy comparisons
#define STEPPER_SPEEDRAMP_STATE_FORWARD        1
#define STEPPER_SPEEDRAMP_STATE_BACKWARD      -1
#define STEPPER_SPEEDRAMP_STATE_STOP           2
#define STEPPER_SPEEDRAMP_STATE_ACCELERATION   3
#define STEPPER_SPEEDRAMP_STATE_RUN            4
#define STEPPER_SPEEDRAMP_STATE_DECELERATION   5

#define STEPPER_DIRECTION_FORWARD   1
#define STEPPER_DIRECTION_BACKWARD -1

#define STEPPER_API_STATE_STOP 1
#define STEPPER_API_STATE_ACCELERATION 2
#define STEPPER_API_STATE_RUN 3
#define STEPPER_API_STATE_DECELERATION 4
#define STEPPER_API_STATE_DIR_CHANGE_FORWARD 5
#define STEPPER_API_STATE_DIR_CHANGE_BACKWARD 6

void new_connection(void);
void stepper_init(void);
void stepper_reset(void);
void stepper_set_output_current(const uint16_t current);
void stepper_set_step_mode(const uint8_t mode);
uint8_t stepper_get_step_mode(void);
void stepper_set_decay(const uint16_t decay);
void stepper_enable(void);
void stepper_disable(void);
void stepper_update_tc_frequency(void);
uint16_t stepper_get_external_voltage(void);
uint16_t stepper_get_stack_voltage(void);
void tick_task(const uint8_t tick_type);
void stepper_set_direction(const int8_t direction);
void stepper_position_reached_signal(void);
bool stepper_is_currently_running(void);
void stepper_set_next_timer(const uint32_t velocity);
void stepper_make_step(void);
void stepper_make_step_speedramp(const int32_t steps);
void stepper_step_speedramp(void);
void stepper_make_drive_speedramp(const uint8_t state);
void stepper_drive_speedramp(void);
void stepper_full_brake(void);
void stepper_check_error_signals(void);
void stepper_set_sync_rect(bool sr);
int32_t stepper_get_remaining_steps(void);
void stepper_all_data_signal(void);
void stepper_state_signal(void);
void stepper_set_new_api_state(const uint8_t new_state);
void stepper_set_configuration(const uint8_t standstill_power_down, const uint8_t chopper_off_time, const uint8_t chopper_hysteresis, const uint8_t chopper_blank_time);

void TC0_IrqHandler(void);



#endif

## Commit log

2015-09-15 add hardware files of silent stepper brick prototype
    [bricklets.sch, power.sch, powersupply.sch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]
2015-09-15 add datasheet of TMC2100 and copied and modified stepper firmware
2015-11-26 fix text positions
    [power.sch, stepper.kicad_pcb, stepper.sch]
2015-12-17 minor changes
    [stepper.kicad_pcb]
2015-12-17 Fix names, versions, etc
    [communication.c, communication.h, config.h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]
2015-12-23 Add Silent Stepper configuration API
2016-02-08 update to new library settings
    [bricklets.sch, power.sch, powersupply.sch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]
2016-02-09 fix tf logo, remove current measurement
    [bricklets.sch, power.sch, powersupply.sch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]
2016-02-09 missing commit, remove current measurement
    [power.sch]
2016-02-11 fix wrong bricklet select voltages
    [bricklets.sch, powersupply.sch, stack.sch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]
2016-02-11 detail routing improvements
    [stepper.kicad_pcb]
2016-02-12 move leds from border, delete to near doku
    [stepper.kicad_pcb]
2016-02-22 fix led config
2016-02-24 remove motor capacitors
    [bricklets.sch, power.sch, powersupply.sch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]
2016-02-25 uncomitted hardware changes
    [stepper.kicad_pcb]
2016-02-25 remove cfg3, add clk connection, imprv gnd routing, 3v3 switchable
    [bricklets.sch, power.sch, powersupply.sch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]
2016-06-13 demo stepper mode switching
    [power.sch, stepper.kicad_pcb]
2016-06-22 changed to tmc2130
    [bricklets.sch, power.sch, powersupply.sch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]
2016-09-06 mark: remove 3v3 mosfet
    [power.sch]
2016-09-16 Basic adjustments for SPI configuration
2016-09-28 Seperate TCM2130 configuration from general stepper handling
2016-10-04 remove unnecessary signals, add external clock
    [bricklets.sch, power.sch, powersupply.sch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]
2016-10-05 change driver type to tmc2130
    [bricklets.sch, power.sch, powersupply.sch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]
2016-10-14 Disable DMA support for now (not working)
    [silent-stepper.c, tcm2130.c]
2016-10-17 change clock series resistor 1k->470
    [power.sch, stepper.kicad_pcb, stepper.sch]
2016-10-18 Add driver status support
2016-10-21 Handle spi read overrun
2016-10-21 turn DMA off after deselect
2016-10-21 Properly handle enable pin after active changes from false to true
2016-10-21 Add active pin handle variables
2016-11-25 swap pins, add series resistors, add clock pi filter
    [bricklets.sch, power.sch, powersupply.sch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]
2016-12-05 Add system timer utility file include to Makefile
2016-12-06 adapt software to current hardware version Change pins of: * leds * spi cs * enable pins
2016-12-15 version before changing to 6 layers
    [bricklets.sch, power.sch, powersupply.sch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]
2016-12-15 change to 6 layer layout
    [stepper.kicad_pcb]
2016-12-16 change routing, remove pi filter
    [bricklets.sch, power.sch, powersupply.sch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]
2016-12-19 drc check
    [stepper.kicad_pcb]
2017-01-09 update fiducials
    [stepper.kicad_pcb]
2017-01-17 change default design to 6layer design
    [bricklets.sch, power.sch, powersupply.sch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]
2017-01-26 Use correct delay for one second at 12.8MHz
    [tcm2130.c]
2017-01-26 Add current output default value (800mA)
2017-01-26 Remove obsolete FIXME comment
    [silent-stepper.c]
2017-01-26 Use correct VREF scaling for maximum current configuration
    [config.h, silent-stepper.c]
2017-04-18 add schematics
    [stepper.kicad_pcb]
2017-04-19 The driver IC is called TMC2130, not TCM2130...
2017-04-19 Add examples
    [ExampleConfiguration.nb.txt]
2017-04-21 Add 3d information (tbc)
    [stepper.kicad_pcb]
2017-04-21 Add most of the 3d information
    [bricklets.sch, power.sch, powersupply.sch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]
2017-04-25 Change D102 to red 3d model
    [stepper.kicad_pcb]
2017-04-25 Change connection footprints
    [stepper.kicad_pcb]
2017-04-28 Fix reordered component paths
    [stepper.kicad_pcb]
2017-04-28 Add Elkos and 4x0603 3d models
    [stepper.kicad_pcb]
2017-05-16 Remove bogus stepper current calculation.
    This erroneously copied from old Stepper Brick.
2017-05-16 Calculate motor current from user set motor run current and actual motor current register.
2017-05-16 Always return 0 for current if stepper is off
2017-05-17 Fix LED color
    [stepper.kicad_pcb]
2017-06-09 Add missing 3d information
    [stepper.kicad_pcb]
2017-06-09 Add 3d model (*.step and *.FCStd)
    [stepper.kicad_pcb]
2017-06-16 Add heatsink to 3d model
    [stepper.kicad_pcb]
2017-12-07 mathematica: Also generate .nb files
    [ExampleConfiguration.nb.txt]
2018-01-11 Increase version number (message duplication bug fix through bricklib)
    [config.h]
2018-02-20 Cleanup KiCad libraries config
    Ensure LibDir=kicad-libraries and LibName1=tinkerforge.
    Remove special library.
2018-05-28 mathematica: Fix namespace
    [ExampleConfiguration.nb.txt]
2018-07-25 Add new 3d model
    [stepper.kicad_pcb]
2018-11-07 rust: Accept host names for ip connection, fix naming inconsistencies
    [example_callback.rs, example_configuration.rs]
2019-01-24 mqtt: Add examples.
    [example-configuration.txt]
2019-01-24 mqtt: Fix example header.
    [example-configuration.txt]
2019-01-24 mqtt: Remove executable bit in example permissions.
    [example-configuration.txt]
2019-01-24 mqtt: Minor example fixes.
    [example-configuration.txt]
2019-08-22 c: Adapt to bindings changes
    [example_callback.c]
2020-01-13 examples: mqtt: Remove trailing whitespace.
    [example-configuration.txt]
2020-03-20 examples: Properly stop motor before disabling motor power
    Disabling motor power while motor is still running could cause
    hardware damage.
    [ExampleConfiguration.nb.txt, example-configuration.txt]
2020-04-07 examples: Add missing imports for sleep calls
    [example_callback.rs, example_configuration.rs]
2020-04-07 examples: rust: Always block when calling bindings functions.
    [example_configuration.rs]
2020-04-07 examples: rust: Block when calling bindings functions.
    [example_callback.rs]
2021-05-03 examples: Fix user data passing to callback
    [example_callback.c]
2021-10-25 Update KiCad link
    https://www.kicad.org/blog/2021/10/Avoid-links-to-former-kicad-domain/
2024-02-21 examples/rust: Fix random number generation.
    [example_callback.rs]
